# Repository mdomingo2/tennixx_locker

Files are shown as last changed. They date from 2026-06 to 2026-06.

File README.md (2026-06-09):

# Tennis-Ball-Machine Locker

A parametric, 3D-printable **open-front locker** sized to hold a tennis ball
machine of **39.2 × 27.1 × 44.8 cm** (D×W×H) with **≥1″ clearance on every
interior face**, built from **20 mm (~0.8″) thick panels** (lightweight variant —
plenty for 20 lb; set `wall=25.4` for the full 1″ version) and rated to carry
the **20 lb** machine.

Because no single panel fits a desktop printer, every panel is **automatically
split into bed-sized tiles** that re-join with **full-length sliding dovetails**.
The five panels (bottom, top, back, two sides) meet at the corners with
**sliding-dovetail housing joints + locking pins**.

Everything is generated from one parametric file: [`src/locker.scad`](src/locker.scad).

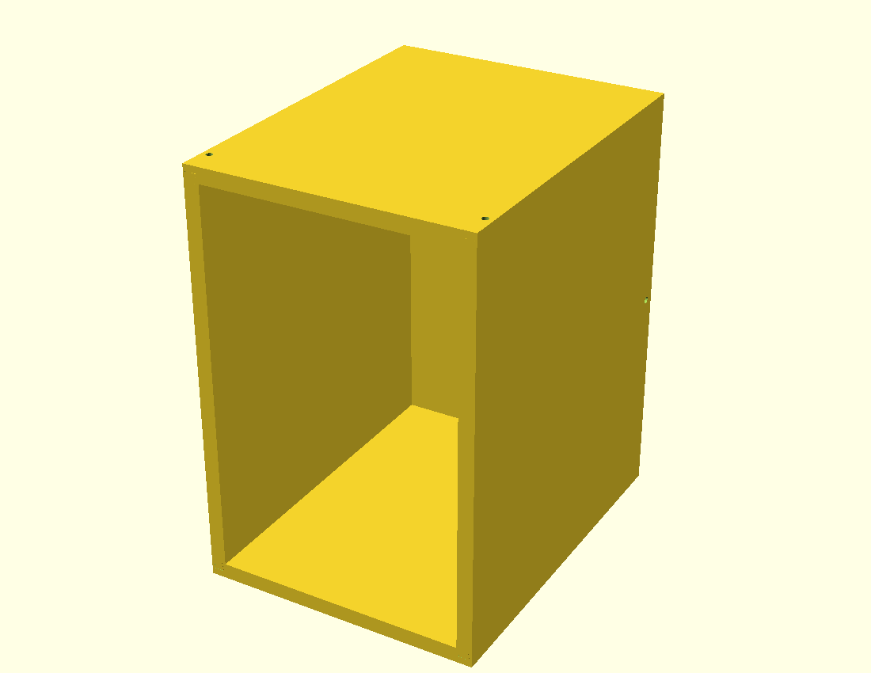
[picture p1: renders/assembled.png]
assembled

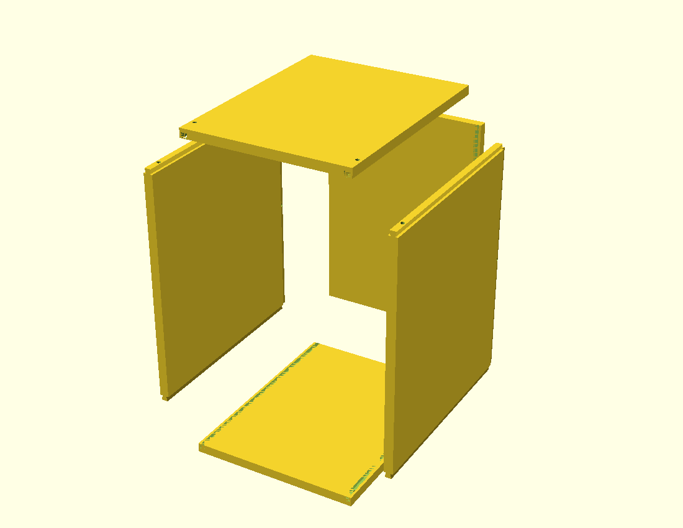
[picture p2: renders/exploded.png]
exploded


Tile-level exploded view — all 30 printable tiles fanned apart along their
sliding-dovetail seams, with the engraved `PANEL-col-row` sort labels visible:

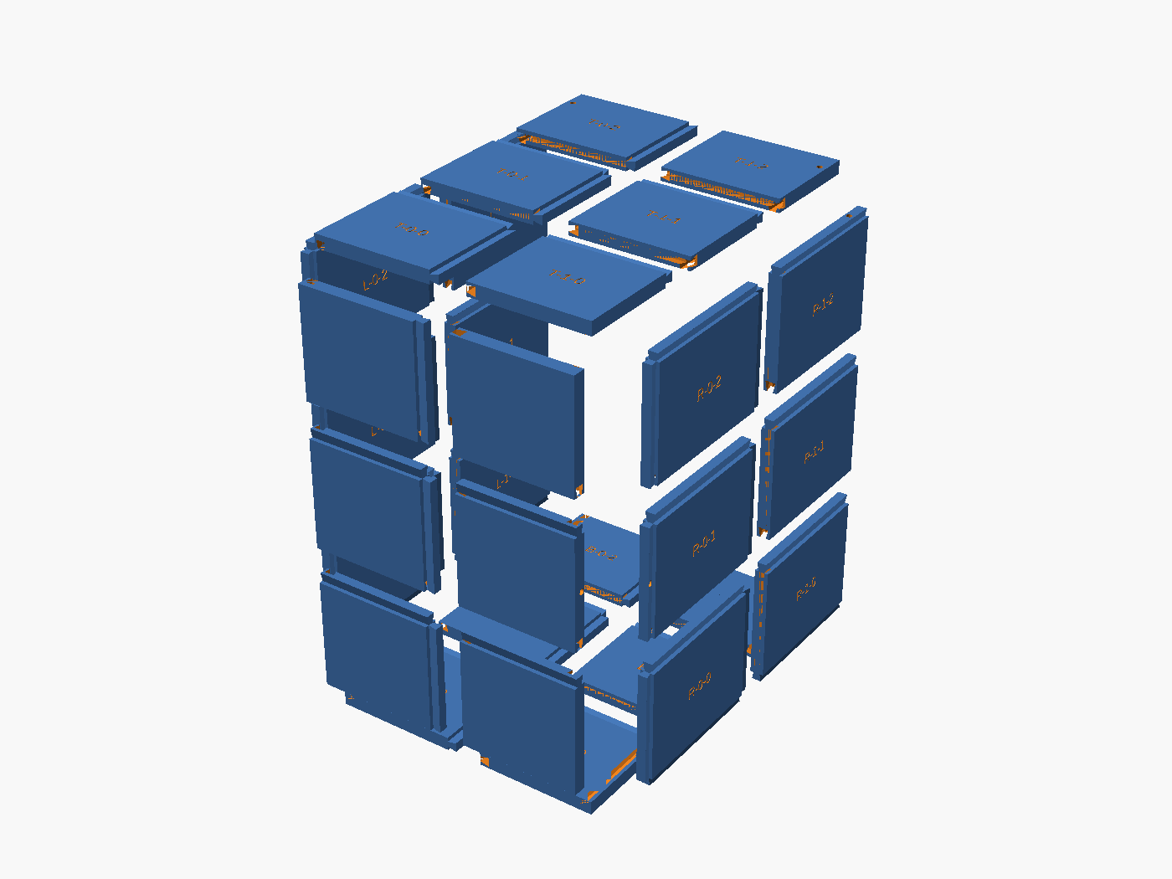
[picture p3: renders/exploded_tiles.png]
exploded tiles


---

## Which tool should I use? → OpenSCAD

| Tool | Verdict for this job |
|---|---|
| **OpenSCAD** ✅ | **Recommended & used here.** The whole design is math: exact dovetail angles, automatic bed-aware tiling, and tolerance fits are all *parameters*. Change the printer or the machine size and the model re-tiles itself. Plain-text → version-controllable in git. |
| **Fusion 360** | Excellent and a fine alternative if you prefer a GUI and want to tweak fillets/aesthetics by hand. But the panel-splitting and 36 dovetail seams would be tedious manual work, and it's not as cleanly version-controlled. Good for *importing* these STLs to validate fit. |
| **Meshy.ai** | ❌ Not suitable. It generates *organic* meshes from text/images and is not dimensionally precise — it cannot hold the ±0.35 mm joint tolerances that make sliding dovetails actually slide and lock. |

---

## Dimensions

| | Width (X) | Depth (Y) | Height (Z) |
|---|---|---|---|
| Object | 271 mm | 392 mm | 448 mm |
| **Interior** (object + 1″ each side) | **321.8** | **442.8** | **498.8** |
| **Exterior** | **361.8** | **462.8** | **538.8** |

- Wall thickness: **20 mm (~0.8″)**
- Front (+Y) is **fully open** so the machine slides straight in.
- Target printer: **Bambu Lab P2S, 256 × 256 × 256 mm** (`print_env` parameter).

## Tile map (30 printable parts)

| Panel | Grid | Tiles | Approx. tile size (mm) |
|---|---|---|---|
| bottom | 2 × 3 | 6 | 181 × 154 × 20 |
| top | 2 × 3 | 6 | 181 × 154 × 20 |
| back | 2 × 3 | 6 | 181 × 166 × 20 |
| left | 2 × 3 | 6 | 221 × 166 × 20 |
| right  | 2 × 3 | 6 | 221 × 166 × 20 |

Sliding-dovetail tongues add ≤14 mm to one or two edges of a tile; all parts
(incl. tongues) stay inside the ~236 mm usable bed.

**Sort labels:** each tile is engraved (1 mm deep) with `PANEL-col-row`, e.g.
`L-0-1`, on the face that prints upward. Panel codes: **B**=bottom, **T**=top,
**K**=back, **L**=left, **R**=right. Toggle with `labels`, size via
`label_size`/`label_depth`.

---

## Generating the parts

OpenSCAD ≥ 2021 required.

```bash
# preview the whole locker / exploded view in the GUI
openscad src/locker.scad                       # then set `mode` in the customizer

# export every printable tile to ./stl  (headless-safe)
./export_stls.sh
```

Render a single thing from the command line by overriding parameters with `-D`:

```bash
# one tile
openscad -o stl/left_0_0.stl -D 'mode="tile"' -D 'which="left"' -D 'ti=0' -D 'tj=0' src/locker.scad
# a whole (un-split) panel, for reference
openscad -o ref/left.stl     -D 'mode="panel"' -D 'which="left"' src/locker.scad
```

`mode` values: `assembled`, `exploded`, `exploded_tiles`, `panel`, `tile`, `alltiles`, `pin`, `pins`.
(`exploded` separates the 5 panels; `exploded_tiles` additionally fans each
panel's print tiles apart along their dovetail seams — gap set by `tile_explode`.)

---

## Print settings (functional, 20 lb load)

- **Material:** PETG or PLA+ (PETG for garage/outdoor temperatures). ASA if UV-exposed.
- **Walls:** 4–5 perimeters. **Infill:** 15–20 % gyroid is ample for 20 lb across 1″ panels.
- **Layer height:** 0.2–0.28 mm.
- **Orientation:** print each tile **flat** (largest face on the bed). The dovetail
  undercuts are shallow (~11–14° from vertical) and print cleanly without supports.
- The bottom-panel tiles carry the load — don't skimp on their perimeters.

**Filament estimate:** ~19,000 cm³ of panel volume → roughly **4.5–6.5 kg** of
filament at 15–20 % infill (the lightweight 20 mm variant). Still a multi-day,
multi-spool project. `wall` is a parameter — raise it to 25.4 for full 1″ panels
or lower it further; the model re-tiles and re-joins automatically.

## Hardware

- **Locking pins:** use 8 mm dowels / M8 bolts, **or print the included pins**
  ([`stl/pins.stl`](stl/pins.stl) — all 6 laid out flat). The corner holes are
  pre-modelled (`pin_d`, `pin_clr`) through every slid joint; the printed pins
  are solid `pin_d` rods (clearance lives in the hole) with a lead-in chamfer.
  There are **6 pins**: 4 short (= panel thickness, `pin_len_v`) at the
  bottom/top side corners and 2 long (`pin_len_h`, 36 mm) at the back corners.
- Optional CA glue or epoxy in the **tile** sliding dovetails for a permanent
  panel; leave the **corner** joints pinned-but-unglued if you want to disassemble.

---

## Assembly order

1. **Build each panel** from its tiles: slide neighbouring tiles together along
   their dovetail seams (a few taps with a mallet; add glue if permanent).
2. **Bottom** flat on the bench.
3. **Slide both side panels** onto the bottom, front-to-back, engaging the
   Y-running dovetails in the bottom's top face.
4. **Drop the back panel** down so its two inner-face vertical dovetail grooves
   engage the rear-edge tenons of the two side panels.
5. **Slide the top** on front-to-back onto the side top tenons.
6. **Insert the 8 mm pins** through each corner joint to lock everything home.

---

## Key parameters (`src/locker.scad`)

| Parameter | Meaning | Default |
|---|---|---|
| `object` | machine [Depth, Width, Height] | `[392, 271, 448]` |
| `clearance` | free space per interior side | `25.4` (1″) |
| `wall` | panel thickness | `20` (lightweight) |
| `print_env` | printer build volume | `[256,256,256]` (P2S) |
| `dt_*` | tile sliding-dovetail size & fit | depth 14, fit 0.35 |
| `mj_*` | corner sliding-dovetail size & fit | depth 11, fit 0.40 |
| `pin_d` | locking pin diameter | 8 |

Change any of these and the part count, tile sizes, and joints all update
automatically. Tune `dt_fit`/`mj_fit` to your printer (smaller = tighter slide).

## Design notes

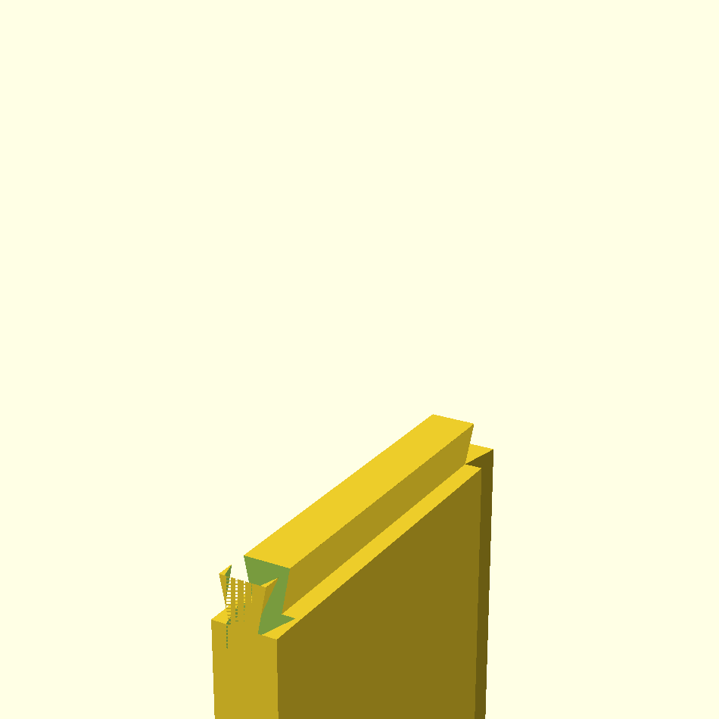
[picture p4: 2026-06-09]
renders/dbg_left00.png

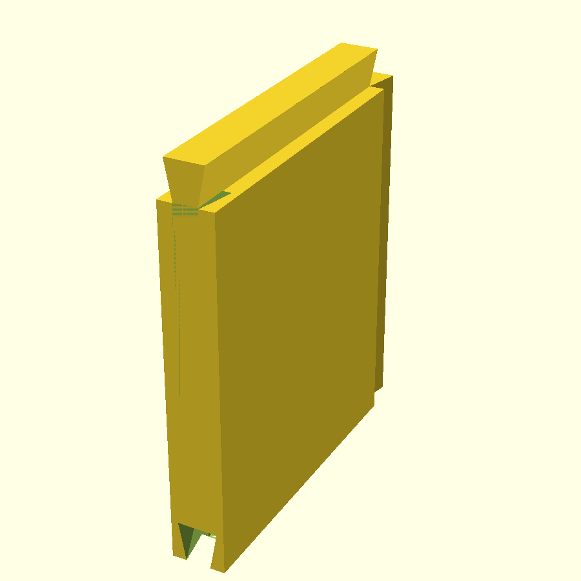
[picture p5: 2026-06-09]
renders/tile_left_11.png

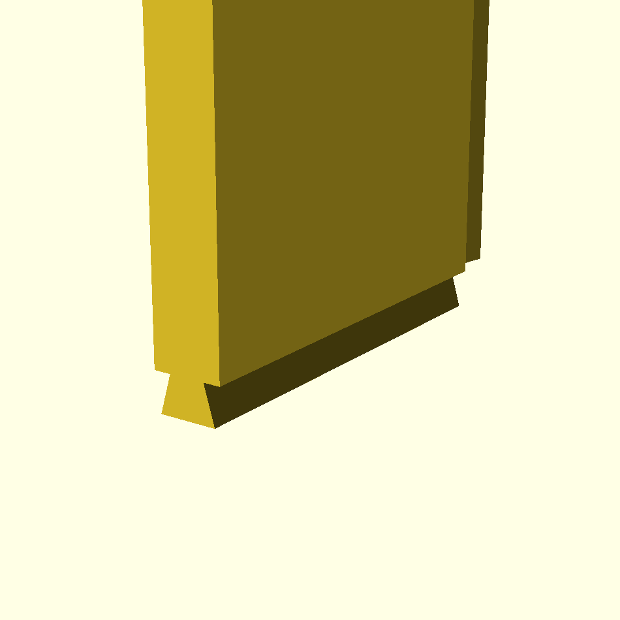
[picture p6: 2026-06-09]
renders/dbg_cj1.png

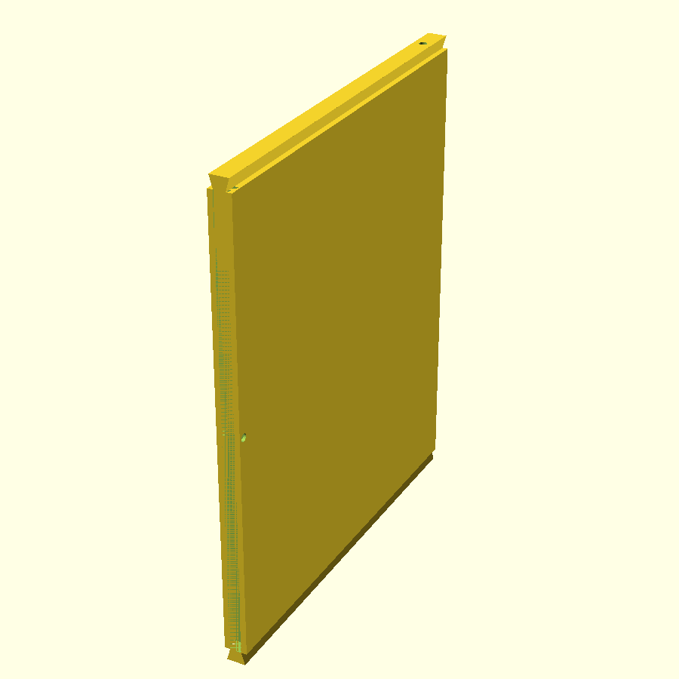
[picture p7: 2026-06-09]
renders/panel_left.png

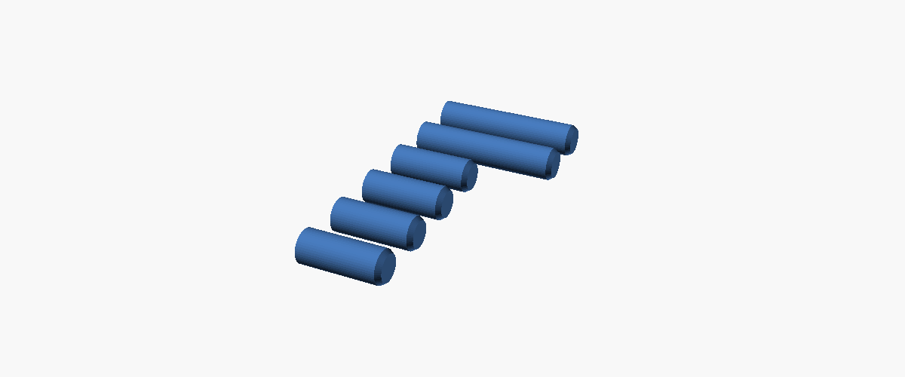
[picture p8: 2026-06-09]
renders/pins.png

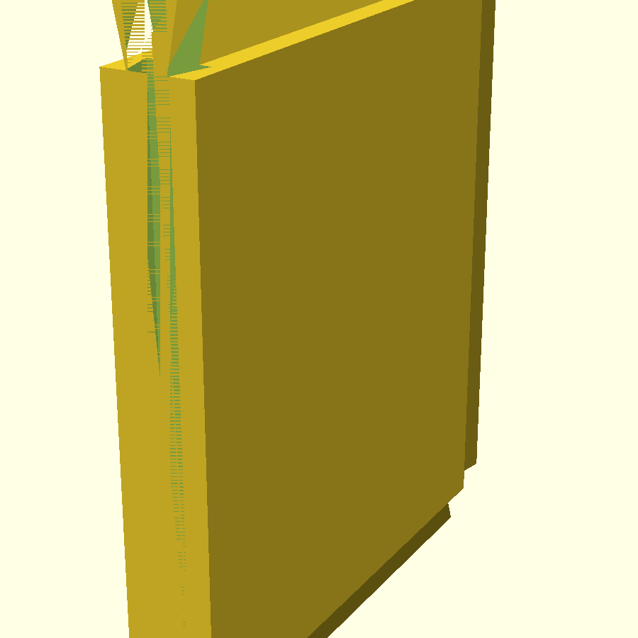
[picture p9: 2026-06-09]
renders/tile_left_00.png

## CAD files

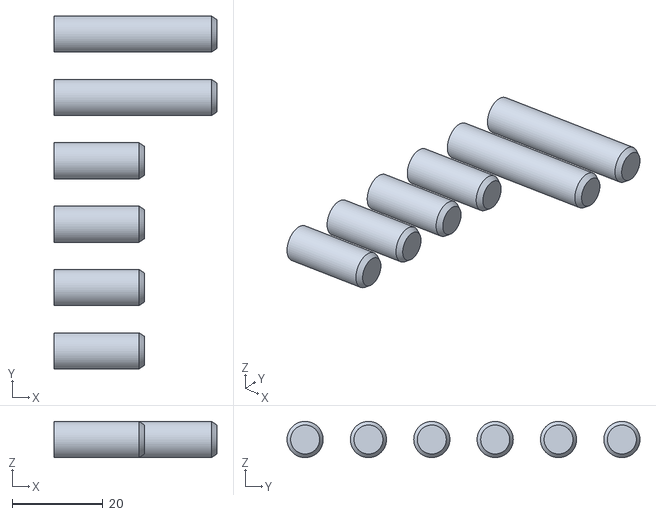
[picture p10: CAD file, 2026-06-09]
stl/pins.stl
36.0 x 78.0 x 8.00

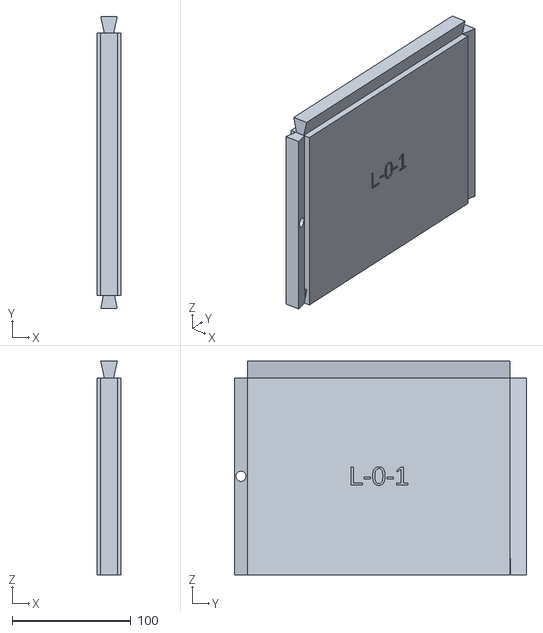
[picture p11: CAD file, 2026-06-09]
stl/left_0_1.stl
20.0 x 246.4 x 180.3

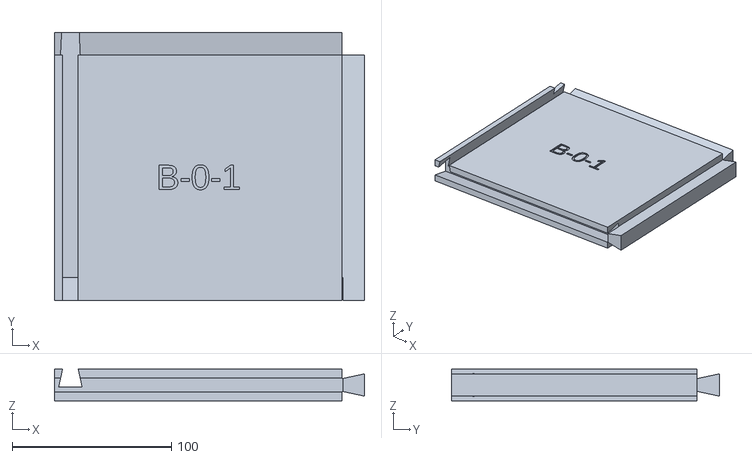
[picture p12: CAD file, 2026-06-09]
stl/bottom_0_1.stl
194.9 x 168.3 x 20.0

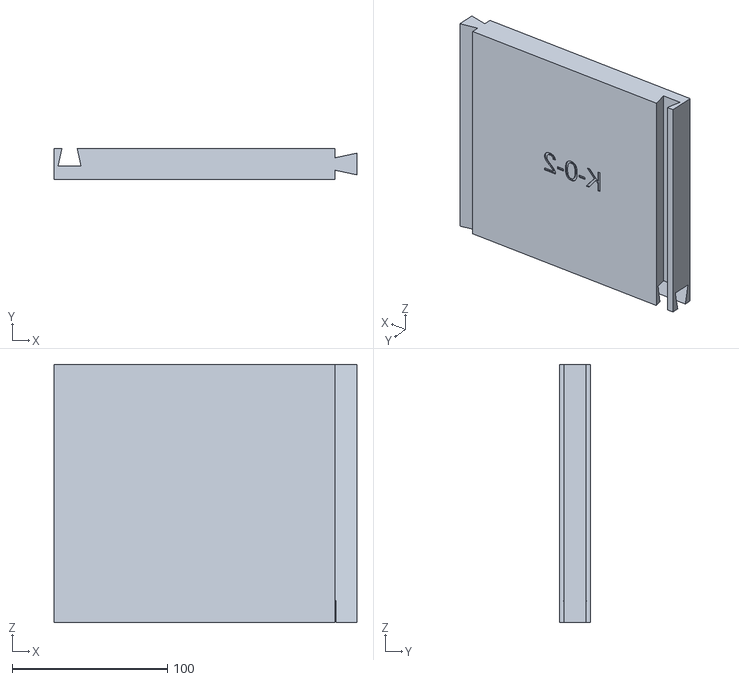
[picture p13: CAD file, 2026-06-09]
stl/back_0_2.stl
194.9 x 20.0 x 166.3

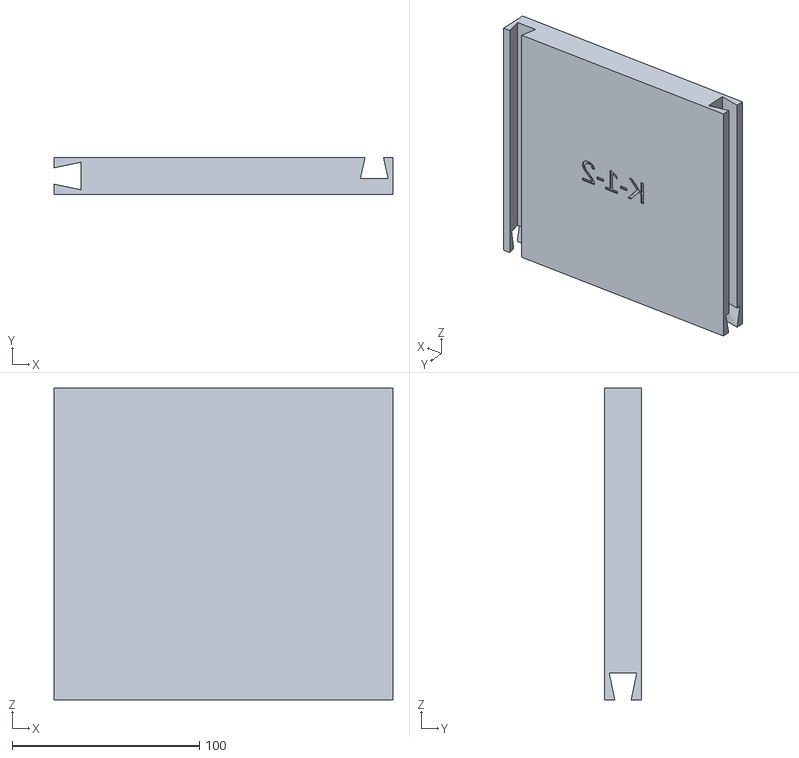
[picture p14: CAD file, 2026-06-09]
stl/back_1_2.stl
180.9 x 20.0 x 166.3

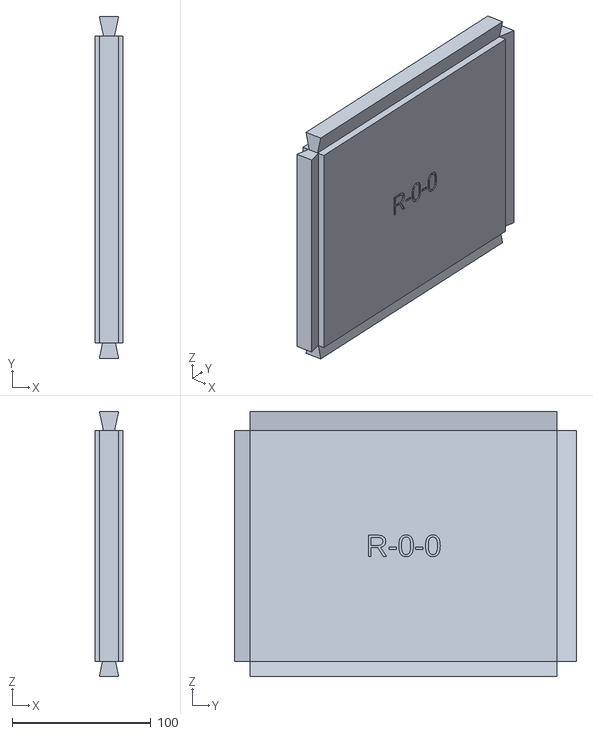
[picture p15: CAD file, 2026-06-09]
stl/right_0_0.stl
20.0 x 246.4 x 191.3

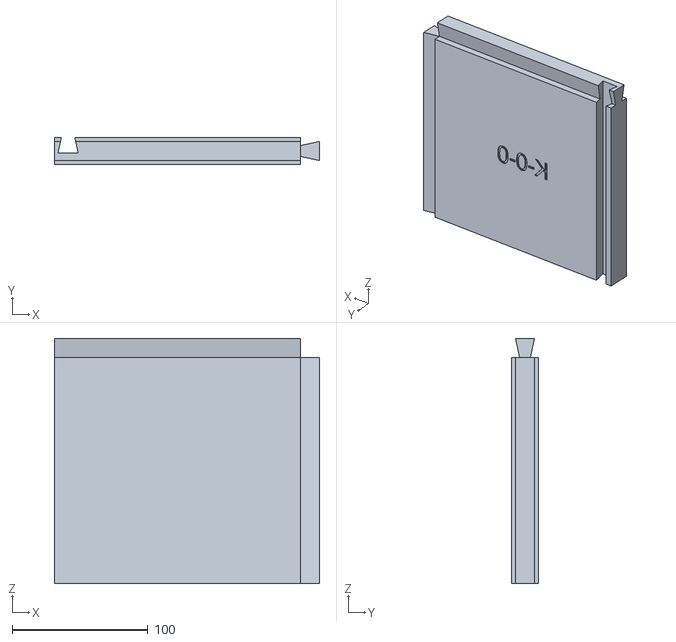
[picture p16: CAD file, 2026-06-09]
stl/back_0_0.stl
194.9 x 20.0 x 180.3

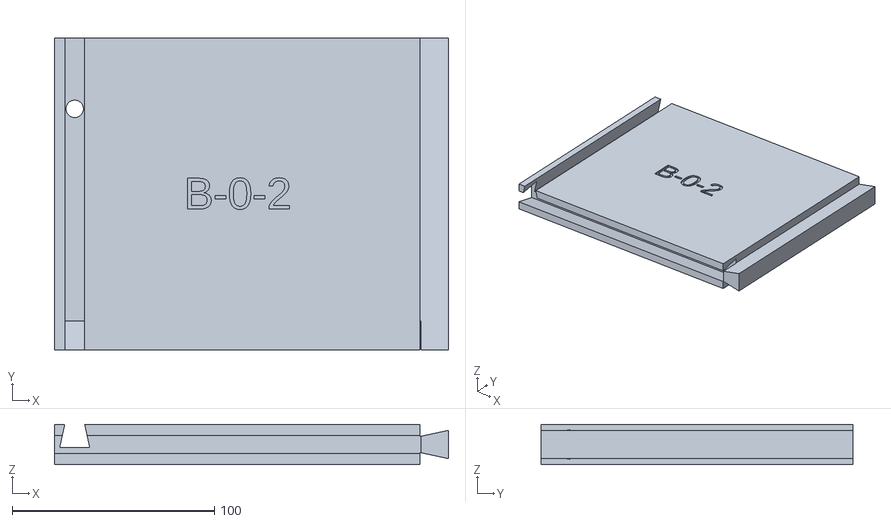
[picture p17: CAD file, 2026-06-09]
stl/bottom_0_2.stl
194.9 x 154.3 x 20.0

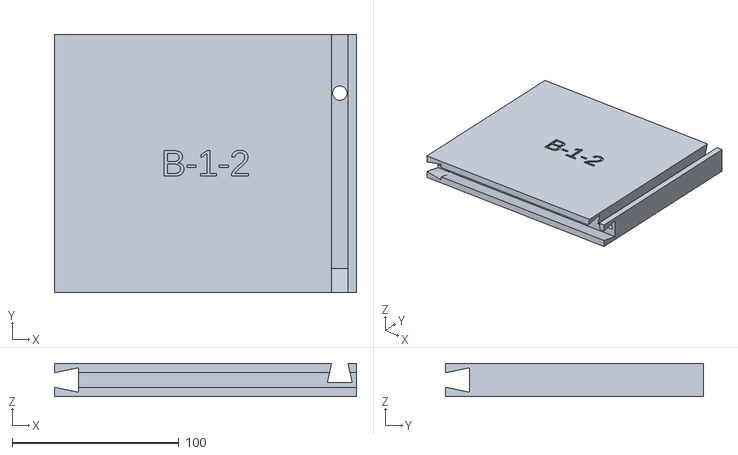
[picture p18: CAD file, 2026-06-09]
stl/bottom_1_2.stl
180.9 x 154.3 x 20.0

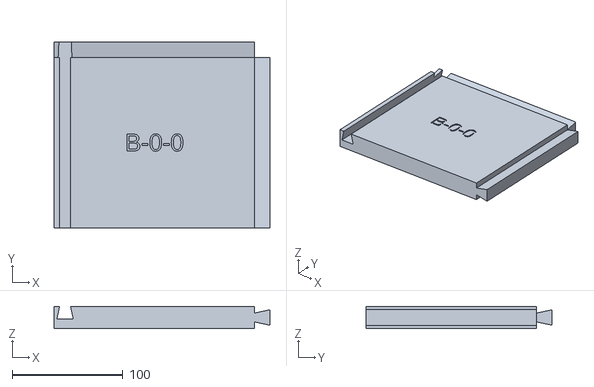
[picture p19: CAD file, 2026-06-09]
stl/bottom_0_0.stl
194.9 x 168.3 x 20.0

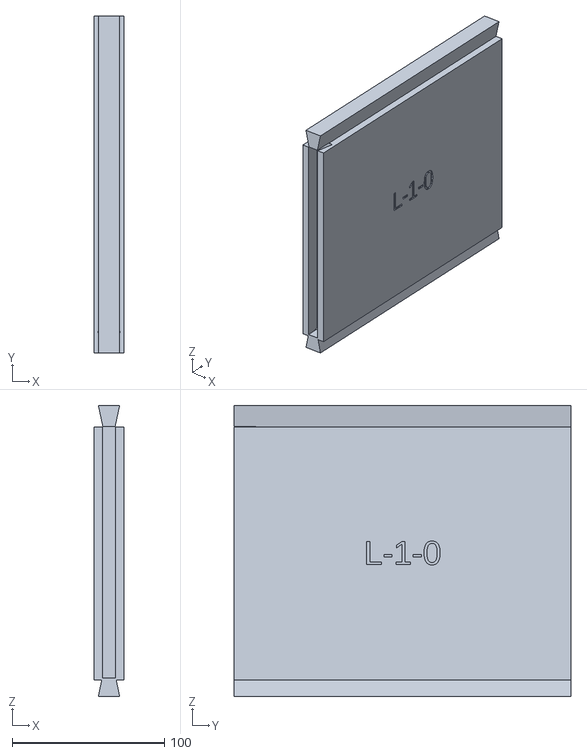
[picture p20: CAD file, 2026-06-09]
stl/left_1_0.stl
20.0 x 221.4 x 191.3

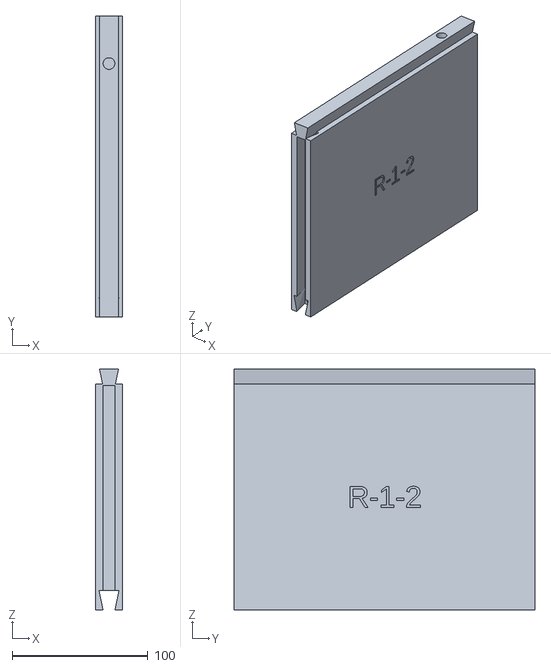
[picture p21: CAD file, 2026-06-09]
stl/right_1_2.stl
20.0 x 221.4 x 177.3

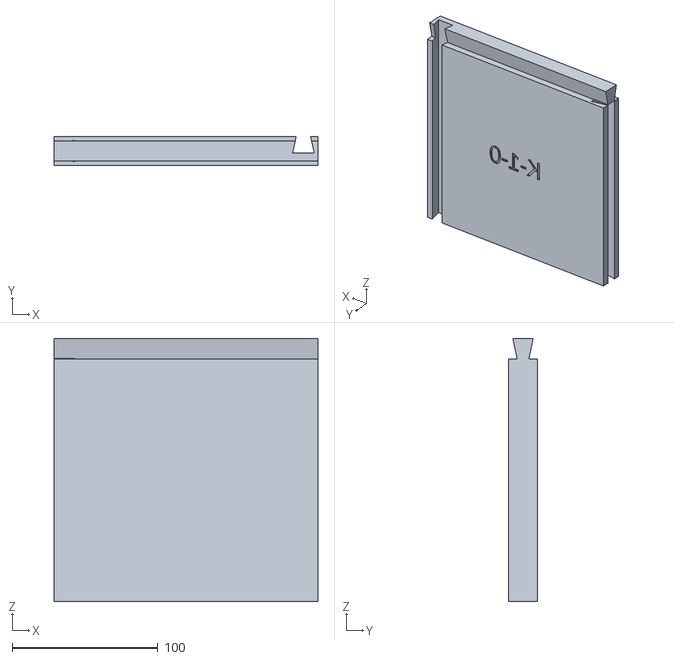
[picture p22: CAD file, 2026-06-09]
stl/back_1_0.stl
180.9 x 20.0 x 180.3

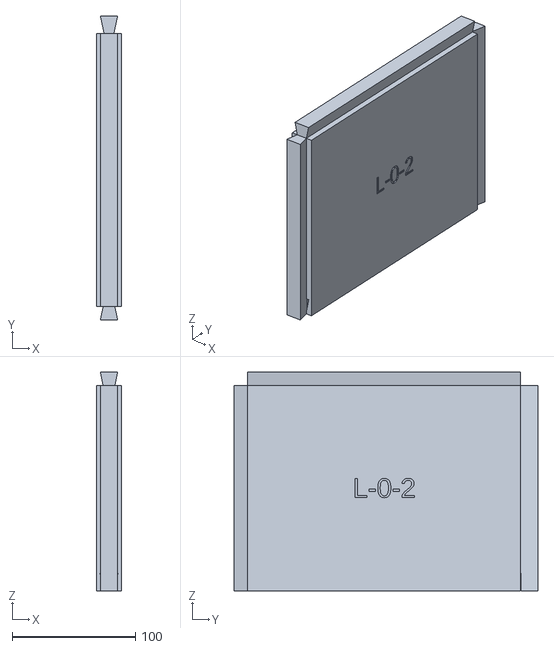
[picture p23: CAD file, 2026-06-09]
stl/left_0_2.stl
20.0 x 246.4 x 177.3

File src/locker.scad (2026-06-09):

// ============================================================================
//  Tennis-ball-machine locker  -  parametric, 3D-printable, sliding-dovetail
// ----------------------------------------------------------------------------
//  Open-front cabinet sized to hold a 39.2 x 27.1 x 44.8 cm machine with >=1"
//  clearance all round. ~1" (25.4 mm) walls. Every panel is auto-split into
//  tiles that fit a Bambu Lab P2S (256^3) bed and re-joined with full-length
//  SLIDING DOVETAILS. The 5 panels meet at the corners with sliding-dovetail
//  housing joints + locking pins.
//
//  Axes:  X = width,  Y = depth (FRONT is open, at +Y),  Z = height (up).
// ============================================================================

$fn = 48;

/* [What to show] */
// "assembled" | "exploded" | "exploded_tiles" | "panel" | "tile" | "pin" | "pins"
mode = "assembled";
// which panel for mode=="panel"/"tile":  bottom top back left right
which = "left";
// tile indices for mode=="tile" (column ti, row tj)
ti = 0;
tj = 0;
// debug: disable corner (panel-to-panel) joints to test tile bodies alone
corner_joints = 2;   // 0=none, 1=tongues only, 2=tongues+grooves+pins

/* ===================== PARAMETERS (mm) ===================== */
object      = [392, 271, 448];   // machine [Depth(X-in), Width, Height]
clearance   = 25.4;              // >= 1" free space on every interior side
wall        = 20;                // panel thickness (lightweight variant; ~0.8")

print_env   = [256, 256, 256];   // Bambu Lab P2S build volume
print_margin= 10;                // keep parts this far from bed edges

// tile-to-tile sliding dovetail (cross-section flares through the wall)
dt_depth = 14;   // how far the tongue reaches into the neighbour
dt_root  = 8;    // neck width (at the seam face)
dt_tip   = 14;   // widest width (locks against in-plane separation); ~3mm walls @20mm
dt_fit   = 0.35; // slide clearance added to every socket face

// main panel-to-panel sliding-dovetail housing joint
mj_depth = 11;   // groove depth into the receiving panel face
mj_root  = 9;    // groove neck width
mj_tip   = 14;   // groove base width (undercut) -> leaves ~3mm walls @20mm
mj_fit   = 0.40; // slide clearance
mj_weld  = 1.2;  // embed tenons this far into their panel (robust CSG merge)

// locking pins (printed or 8 mm dowel) that pin every slid joint home
pin_d    = 8;
pin_clr  = 0.30;

// sort labels engraved into each tile  (B=bottom T=top K=back L=left R=right)
labels      = true;
label_size  = 16;   // text height (mm)
label_depth = 1.0;  // engrave depth (mm)

explode  = 90;   // gap used by mode=="exploded"/"exploded_tiles" (panels apart)
tile_explode = 55;   // extra gap between neighbouring tiles in mode=="exploded_tiles"

/* ===================== DERIVED ===================== */
inW = object[1] + 2*clearance;        // interior width   (X)
inD = object[0] + 2*clearance;        // interior depth   (Y)
inH = object[2] + 2*clearance;        // interior height  (Z)

outW = inW + 2*wall;                  // overall width
outD = inD + wall;                    // overall depth (back wall only)
outH = inH + 2*wall;                  // overall height

usable  = min(print_env[0], print_env[1]) - 2*print_margin;  // bed area limit
usableZ = print_env[2] - print_margin;                       // bed height limit
cellmax = usable - dt_depth;          // leave room for the protruding tongue

// tile count for a given panel edge length
function ntiles(L) = max(1, ceil(L / cellmax));

/* ===================== DOVETAIL PRIMITIVE ===================== */
// Canonical sliding-dovetail prism:
//   length `len` runs along +Y, grows from `root` to `tip` (in X) as it goes
//   0 -> `depth` along +Z.  i.e. run=Y, depth=+Z, flare=X.
module dt_canon(len, depth, root, tip) {
    hull() {
        translate([-root/2, 0, 0      ]) cube([root, len, 0.02]);
        translate([-tip/2,  0, depth-0.02]) cube([tip,  len, 0.02]);
    }
}

/* ===================== GENERIC TILED PANEL =====================
   Built in a LOCAL frame: the panel lies in the (u,v) plane, thickness `t`
   along +n(=local Z). Split into nu x nv tiles. Tile carries a male dovetail
   on its +u and +v edges and a female socket on its -u and -v edges, so
   neighbours interlock. `cell` returns one tile; `whole` returns the slab. */

// male tongue on the +U seam (runs along V, flares through thickness Z)
module tongueU(x, y0, len, t) {
    translate([x, y0, t/2]) rotate([0,90,0]) dt_canon(len, dt_depth, dt_root, dt_tip);
}
// permutation that maps canon (run=Y,depth=Z,flare=X) -> (run=X,depth=Y,flare=Z)
PV = [[0,1,0,0],[0,0,1,0],[1,0,0,0],[0,0,0,1]];
// male tongue on the +V seam (runs along U, flares through thickness Z)
module tongueV(x0, y, len, t) {
    translate([x0, y, t/2]) multmatrix(PV) dt_canon(len, dt_depth, dt_root, dt_tip);
}
// matching sockets (same shape, grown by fit)
module socketU(x, y0, len, t) {
    translate([x, y0, t/2]) rotate([0,90,0])
        dt_canon(len+2*dt_fit, dt_depth+dt_fit, dt_root+2*dt_fit, dt_tip+2*dt_fit);
}
module socketV(x0, y, len, t) {
    translate([x0, y, t/2]) multmatrix(PV)
        dt_canon(len+2*dt_fit, dt_depth+dt_fit, dt_root+2*dt_fit, dt_tip+2*dt_fit);
}

module tile_local(Lu, Lv, t, nu, nv, i, j, lbl="") {
    cu = Lu/nu;  cv = Lv/nv;
    difference() {
        union() {
            translate([i*cu, j*cv, 0]) cube([cu, cv, t]);
            if (i < nu-1) tongueU((i+1)*cu, j*cv, cv, t);
            if (j < nv-1) tongueV(i*cu, (j+1)*cv, cu, t);
        }
        if (i > 0) socketU(i*cu, j*cv - dt_fit, cv, t);
        if (j > 0) socketV(i*cu - dt_fit, j*cv, cu, t);
        // engrave the sort label into the (local +Z) face that prints upward
        if (labels && lbl != "")
            translate([(i+0.5)*cu, (j+0.5)*cv, t - label_depth])
                linear_extrude(label_depth + 0.1)
                    text(lbl, size=label_size, halign="center", valign="center");
    }
}

module slab_local(Lu, Lv, t) { cube([Lu, Lv, t]); }

/* ===================== PANEL PLACEMENT ===================== */
// Each panel is described by a world origin O and an orthonormal basis
// (U,V = in-plane, N = +thickness).  One engine, five panels.
function pO (n)= n=="bottom"?[0,0,0] : n=="top"?[0,0,outH-wall] :
                 n=="back"?[0,0,wall] : n=="left"?[0,wall,wall] : [outW-wall,wall,wall];
function pU (n)= (n=="bottom"||n=="top"||n=="back")?[1,0,0]:[0,1,0];
function pV (n)= (n=="bottom"||n=="top")?[0,1,0]:[0,0,1];
function pN (n)= (n=="bottom"||n=="top")?[0,0,1]: n=="back"?[0,1,0]:[1,0,0];
function pLu(n)= (n=="bottom"||n=="top"||n=="back")?outW:inD;
function pLv(n)= (n=="bottom"||n=="top")?outD:inH;
function pAbbr(n)= n=="bottom"?"B": n=="top"?"T": n=="back"?"K": n=="left"?"L":"R";

module place(n) {
    U=pU(n); V=pV(n); N=pN(n); O=pO(n);
    multmatrix([[U[0],V[0],N[0],O[0]],
                [U[1],V[1],N[1],O[1]],
                [U[2],V[2],N[2],O[2]],
                [0,0,0,1]]) children();
}

/* ===================== MAIN (CORNER) SLIDING-DOVETAIL JOINTS =====================
   - sides drop onto the bottom / under the top via Y-running dovetails
   - the back drops down into vertical dovetails cut in the side rear faces
   - every slid joint is locked with an 8 mm pin                              */
// tenons are extended by mj_weld on the neck side so they embed into (overlap)
// their own panel -> the CSG union is a solid merge, not a coplanar touch.
// Grooves are channels in the BROAD faces of the bottom/top/back panels;
// tenons are rails on the SIDE-panel edges. Cutting grooves only into wide
// panels (never the thin side walls) keeps every tile a single solid.
module groove_bottom(cx){ translate([cx,0,wall])           rotate([0,180,0]) dt_canon(outD, mj_depth+mj_fit, mj_root+2*mj_fit, mj_tip+2*mj_fit); }
module tenon_bottom (cx){ translate([cx,wall,wall+mj_weld]) rotate([0,180,0]) dt_canon(inD,  mj_depth+mj_weld, mj_root,        mj_tip); }
module groove_top   (cx){ translate([cx,0,outH-wall])                         dt_canon(outD, mj_depth+mj_fit, mj_root+2*mj_fit, mj_tip+2*mj_fit); }
module tenon_top    (cx){ translate([cx,wall,outH-wall-mj_weld])              dt_canon(inD,  mj_depth+mj_weld, mj_root,        mj_tip); }
module back_groove  (cx){ translate([cx,wall,wall])         rotate([90,0,0])  dt_canon(inH,  mj_depth+mj_fit, mj_root+2*mj_fit, mj_tip+2*mj_fit); }
module side_rear_tenon(cx){ translate([cx,wall+mj_weld,wall]) rotate([90,0,0]) dt_canon(inH, mj_depth+mj_weld, mj_root,        mj_tip); }

module tongues(n){
    if(n=="left")  { tenon_bottom(wall/2);      tenon_top(wall/2);      side_rear_tenon(wall/2); }
    if(n=="right") { tenon_bottom(outW-wall/2); tenon_top(outW-wall/2); side_rear_tenon(outW-wall/2); }
}
module grooves(n){
    if(n=="bottom"){ groove_bottom(wall/2);  groove_bottom(outW-wall/2); }
    if(n=="top")   { groove_top(wall/2);     groove_top(outW-wall/2); }
    if(n=="back")  { back_groove(wall/2);    back_groove(outW-wall/2); }
}
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

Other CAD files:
stl/left_0_0.stl
stl/right_0_1.stl
stl/right_1_0.stl
stl/top_1_0.stl
stl/back_0_1.stl
stl/back_1_1.stl
stl/bottom_1_0.stl
stl/bottom_1_1.stl
stl/left_1_1.stl
stl/left_1_2.stl
stl/right_0_2.stl
stl/right_1_1.stl
stl/top_0_0.stl
stl/top_0_1.stl
stl/top_0_2.stl
stl/top_1_1.stl
stl/top_1_2.stl

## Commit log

2026-06-09 Parametric sliding-dovetail locker for tennis ball machine
    Open-front cabinet (1in walls) sized to a 39.2x27.1x44.8 cm machine with 1in
    clearance all round. Auto-splits each panel into Bambu Lab P2S (256^3)
    bed-sized tiles joined by full-length sliding dovetails; the five panels meet
    at sliding-dovetail corner joints with locking pins. All 36 tiles verified as
    single 2-manifold solids.
    [back_0_0.stl, back_0_1.stl, back_0_2.stl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]
2026-06-09 Switch to lightweight 20mm-wall variant (30 tiles)
    - wall 25.4 -> 20mm; dovetails rescaled to keep >=3mm cheeks
    - flip back<->side corner joint: tenon on side rear edge, groove in back
    inner face (channels in broad panels never fragment thin side tiles)
    - all panels now 2x3 (30 tiles); every tile + the assembled model verified
    as a single 2-manifold solid
    - README updated (dims, tile map, ~4.5-6.5kg filament estimate)
    [back_0_0.stl, back_0_1.stl, back_0_2.stl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]
2026-06-09 Engrave sort labels (PANEL-col-row) into each tile
    Each tile gets a 1mm-deep label (e.g. L-0-1) on the upward-printing face;
    codes B/T/K/L/R. Toggle via 'labels' parameter. All tiles remain single
    2-manifold solids.
    [back_0_0.stl, back_0_1.stl, back_0_2.stl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]
2026-06-09 Add tile-level exploded view (exploded_tiles mode + render)
    [locker.scad]
2026-06-09 Add printable locking pins (pins.stl + pin/pins modes)
    [locker.scad, pins.stl]
